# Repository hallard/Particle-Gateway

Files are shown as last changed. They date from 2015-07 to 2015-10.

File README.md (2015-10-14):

Particle (formerly Spark) Gateway
=================================

Edit October 2015 : New Revision 1.0a with better SMA connector for RF module

The gateway can host several funny things like

- Socket to plug a Spark Core or Particle Photon
- Pins to connect I2C or SPI OLED 128x64
- Pins to connect 2.2" or 1.8" TFT LCD
- RFM69 or RFM12B on board module
- Lipo Battery connector for testing and move the Gateway (no charger on board)
- 3V3 On board regulator for harvesting devices if any to avoid pumping from Particle Regulator
- Data connection for any cheap ebay ASK RX receiver
- FTDI connection for those who want to debug serial or send data over real serial
- 2 x grove I2C connector to connect other I2C devices

Detailed Description
====================

Everything is documented on this dedicated [post][1] 

### Schematic  
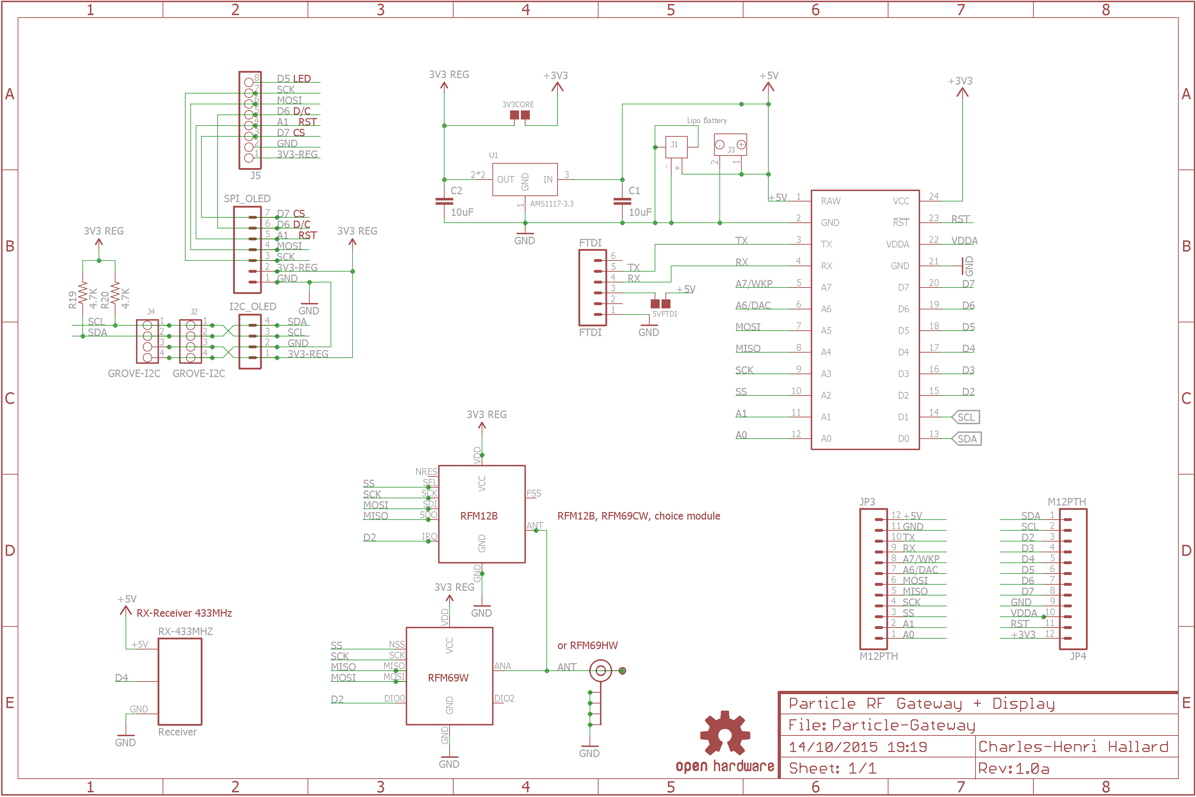
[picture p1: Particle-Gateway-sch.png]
schematic
  

### Bill Of Material
Reference from Seeedstudio [Open Part Libray][8] SKU but can be ordered on any provider, Digikey, Mouser. Link to the [BOM][6] file.    

For SPARK connector I use IC socket that I cut on needed size, for other connectors, I usually buy 40 pins headers (male and female) on ebay that I cut at the needed size. [Example][7]

### Boards  
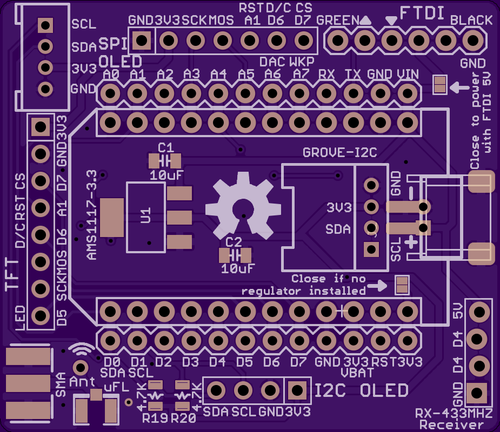
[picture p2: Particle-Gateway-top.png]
Top
&nbsp;
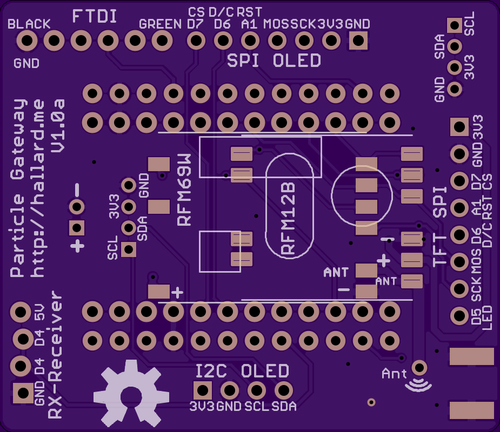
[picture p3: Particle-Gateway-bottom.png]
Bottom
&nbsp; 

You can order the PCB of this board at [OSHPARK][5]

### Assembled boards

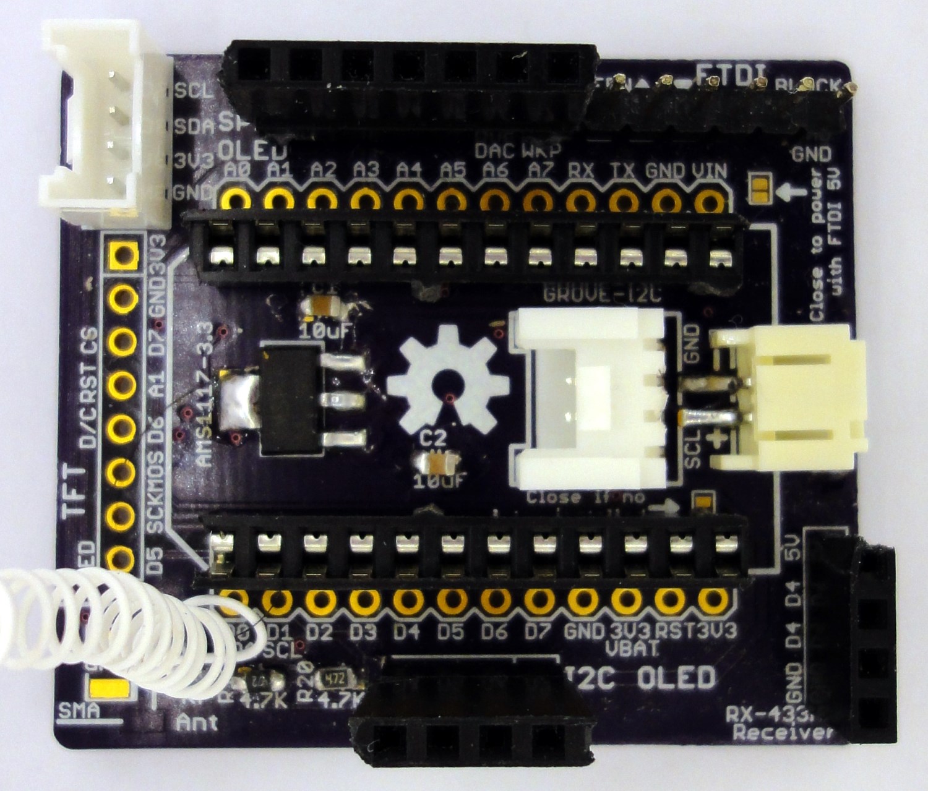
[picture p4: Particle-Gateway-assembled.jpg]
Assembled TOP
&nbsp;
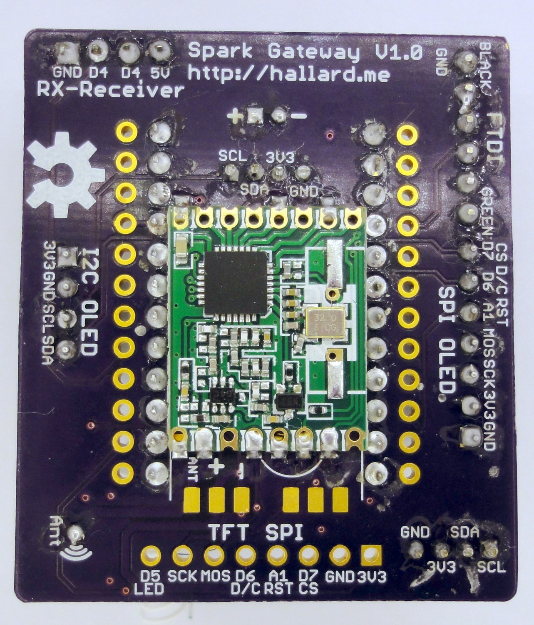
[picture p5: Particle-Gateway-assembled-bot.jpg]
Assembled Bottom

OLED&nbsp; 

##License

You can do whatever you like with this design.

##Misc
See news and other projects on my [blog][2] 
 
[1]: https://hallard.me/particle-gateway/
[2]: https://hallard.me
[3]: https://github.com/thibdct/programmateur-fil-pilote-wifi/tree/master/Logiciel/remora
[4]: http://lowpowerlab.com/blog/2013/06/20/rfm69-library/
[5]: https://oshpark.com/shared_projects/S3Dmdwhs
[6]: https://github.com/hallard/Particle-Gateway/blob/master/Particle-Gateway-BOM.xlsx?raw=true
[7]: http://stores.ebay.com/jkpartsstore/Connectors-Sockets-/_i.html?_fsub=1665035011
[8]: http://www.seeedstudio.com/depot/OPLopen-parts-library-catalog-c-136_138/?ref=side

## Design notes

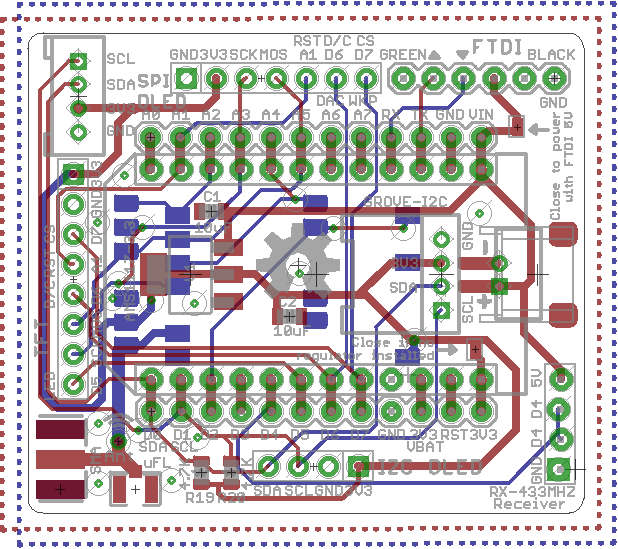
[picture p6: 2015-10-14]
Particle-Gateway-board.png

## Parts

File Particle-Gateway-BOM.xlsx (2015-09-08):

Part | Value | Device | Package | Description | SEEEDSTUDIO OPL SKU
C1 | 10uF | CAP0805-CAP | 0805-CAP | Capacitor | 302010178 (http://www.seeedstudio.com/depot/index.php?main_page=opl_info&opl_id=7)
C2 | 10uF | CAP0805-CAP | 0805-CAP | Capacitor | 302010178 (http://www.seeedstudio.com/depot/index.php?main_page=opl_info&opl_id=7)
FTDI | FTDI | M06SIP | 1X06 | 6x2.54mm male header | 320020078 (http://www.seeedstudio.com/depot/index.php?main_page=opl_info&opl_id=96)
I2C_OLED | CON_HEADER_1X04'SMALL'' | CON_HEADER_1X04'SMALL'' | M1X4 | 4x2.54mm Female connector | 320030017 (http://www.seeedstudio.com/depot/index.php?main_page=opl_info&opl_id=237)
J1 |  | JST-2P-SMD'2.0' | 2P-SMD-2.0-90D | Battery Connector (Use J1 or J3 not both) | 320110027 (http://www.seeedstudio.com/depot/index.php?main_page=opl_info&opl_id=64)
J2 | GROVE-I2C | GROVE-4P-2.0-3470140P1 | 4P-2.0-90D | Grove connector | 320110034 (http://www.seeedstudio.com/depot/index.php?main_page=opl_info&opl_id=24)
J3 | Lipo Battery | JST-2P-PW-3410070P1 | 2P-2.0-90D | Battery Connector (Use J1 or J3 not both) | 320110026 (http://www.seeedstudio.com/depot/index.php?main_page=opl_info&opl_id=37)
J4 | GROVE-I2C | GROVE-4P-2.0-3470130P1 | 4P-2.0 | Grove connector | 320110033 (http://www.seeedstudio.com/depot/index.php?main_page=opl_info&opl_id=4)
J5 | CON_HEADER_1X08-PTH | CON_HEADER_1X08-PTH | M1X8 | 8x2.54mm Female connector | 320030061 (http://www.seeedstudio.com/depot/index.php?main_page=opl_info&opl_id=95)
JP3 | M12PTH | M12PTH | 1X12-SMALL-PADS | Header 12
JP4 | M12PTH | M12PTH | 1X12-SMALL-PADS | Header 12
R19 | 4.7K | RESISTOR0805-RES | 0805-RES | Resistor | 301010306 (http://www.seeedstudio.com/depot/index.php?main_page=opl_info&opl_id=260)
R20 | 4.7K | RESISTOR0805-RES | 0805-RES | Resistor | 301010306 (http://www.seeedstudio.com/depot/index.php?main_page=opl_info&opl_id=260)
SPI_OLED | CON_HEADER_1X07'SMALL' | CON_HEADER_1X07'SMALL' | M1X7 | 7x2.54mm Female connector | 320020093 (http://www.seeedstudio.com/depot/index.php?main_page=opl_info&opl_id=997)
U1 | AMS1117-3.3 | CJ1117-3.3-1310190P1 | SOT223 | 3V3 1A Low Dropout Linear Regulator | 310030097 (http://www.seeedstudio.com/depot/index.php?main_page=opl_info&opl_id=33)

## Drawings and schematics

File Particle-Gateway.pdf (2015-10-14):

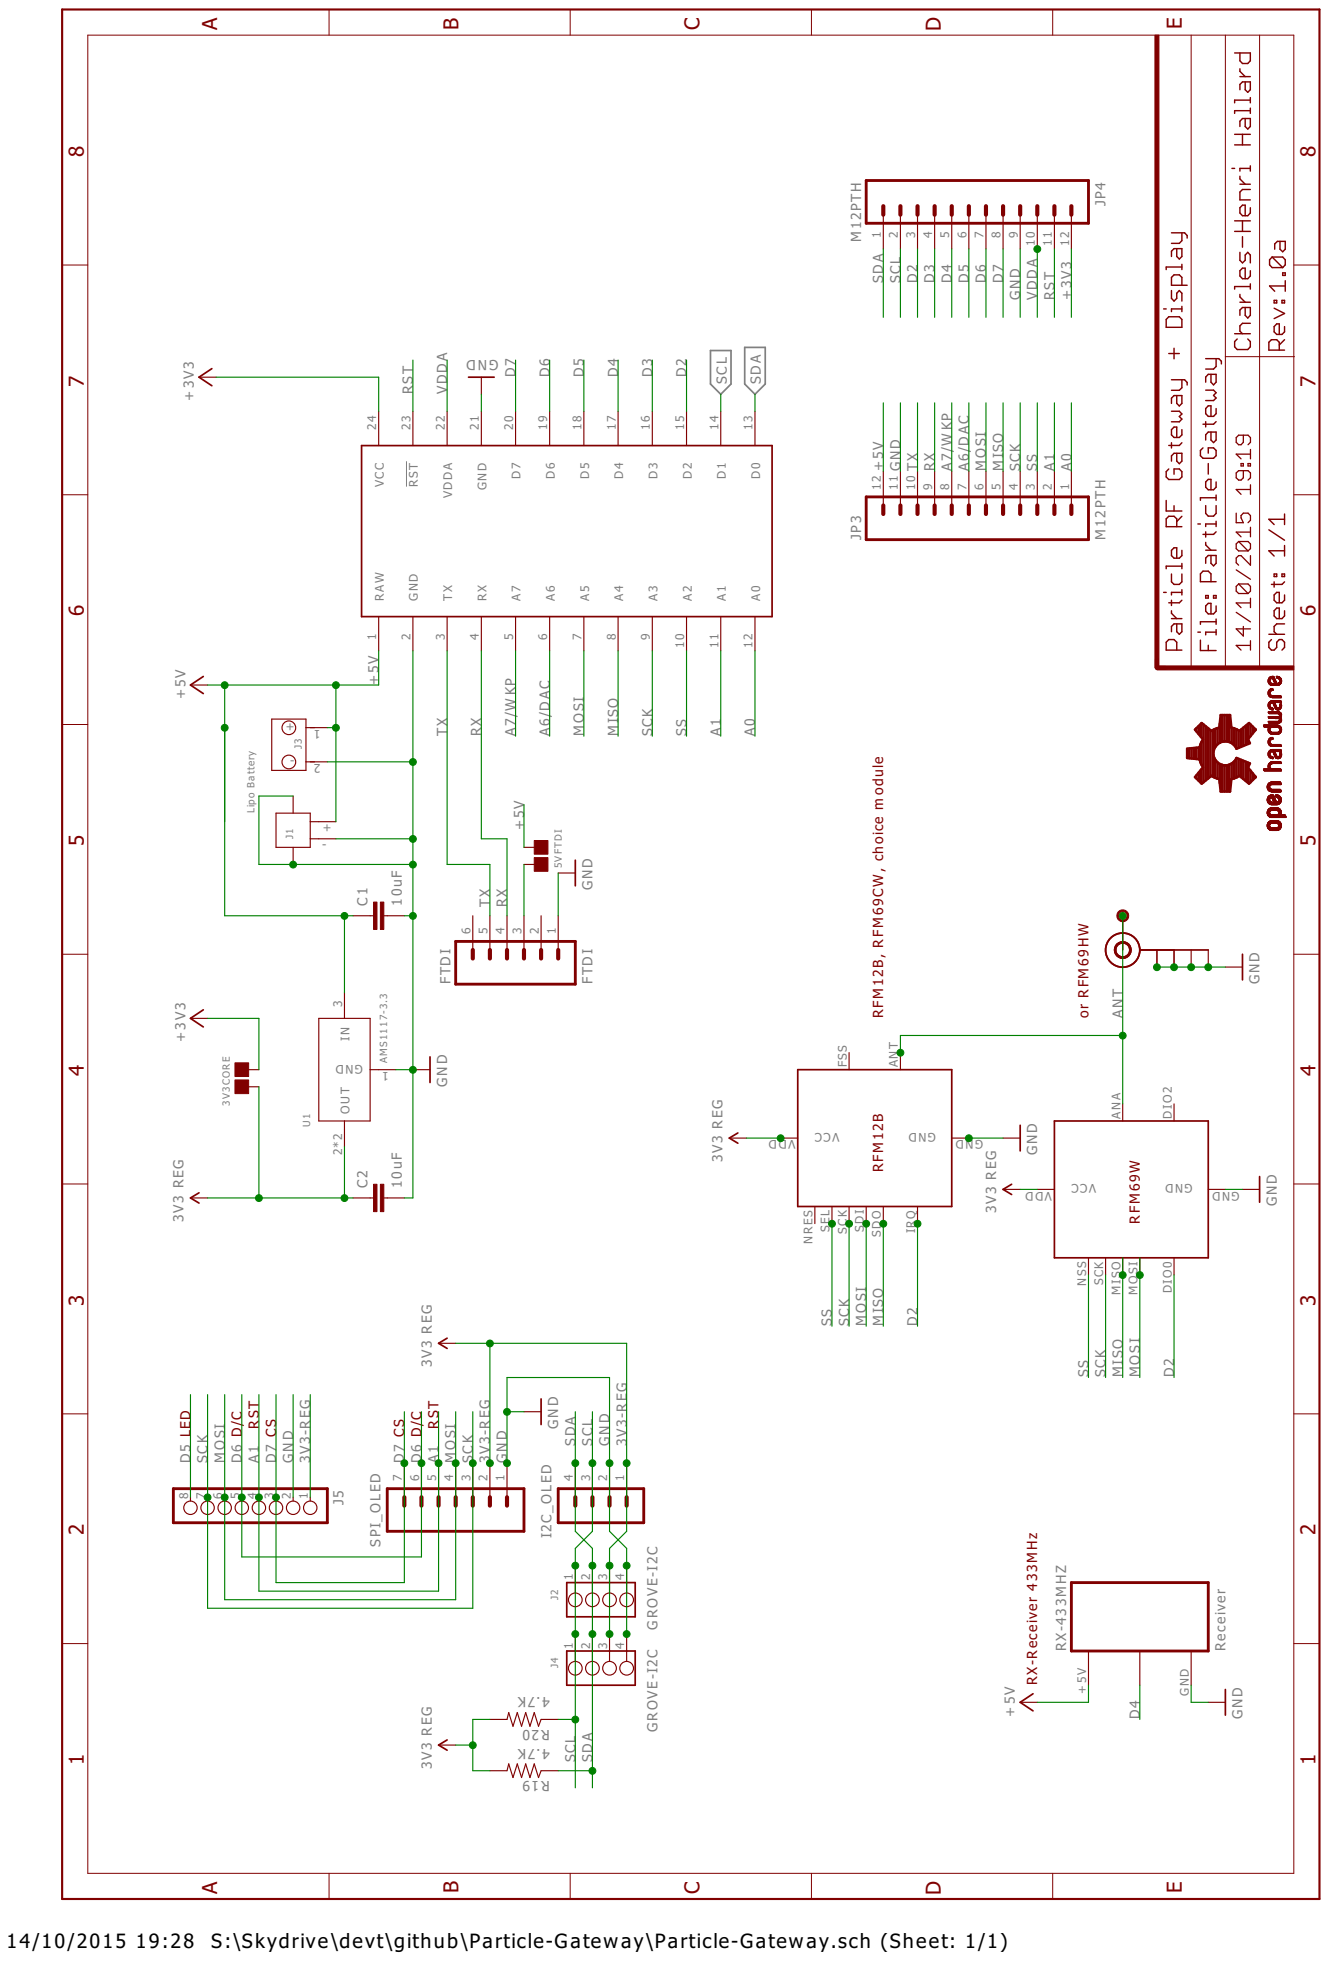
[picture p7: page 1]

MISO MOSI SCK NSS CCV DDV

14/10/2015 19:28 S:\Skydrive\devt\github\Particle-Gateway\Particle-Gateway.sch (Sheet: 1/1)

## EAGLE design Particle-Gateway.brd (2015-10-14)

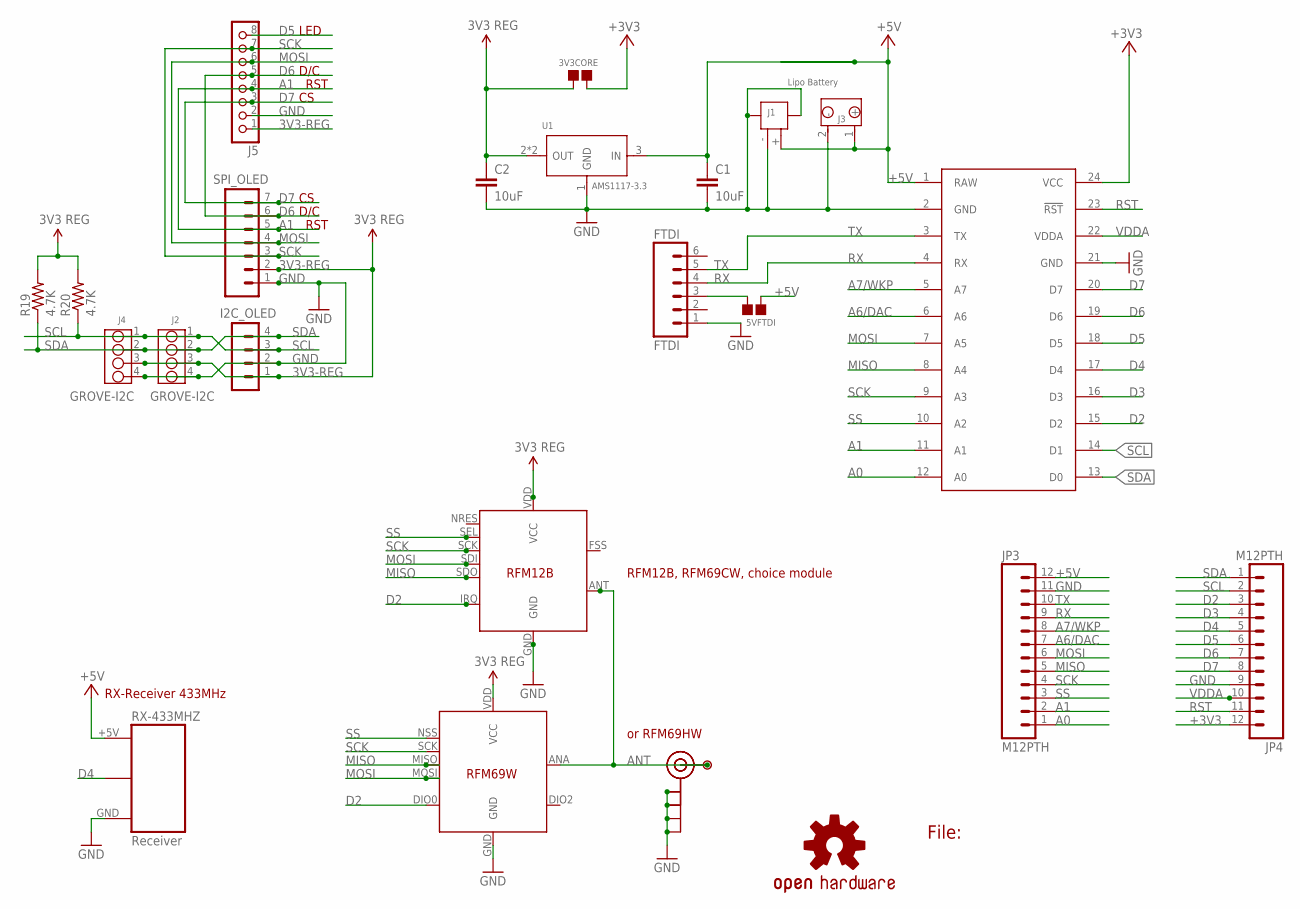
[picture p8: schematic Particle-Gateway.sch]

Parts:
3V3CORE, 5VFTDI: PAD-JUMPER-2P; 2P-SMD-1.78X1.27
C1, C2: 10uF; 0805-CAP
FTDI: FTDI; 1X06
I2C_OLED: CON_HEADER_1X04'SMALL''; M1X4
J1: JST-2P-SMD'2.0'; 2P-SMD-2.0-90D
J2: GROVE-I2C; 4P-2.0-90D
J3: Lipo Battery; 2P-2.0-90D
J4: GROVE-I2C; 4P-2.0
J5: CON_HEADER_1X08-PTH; M1X8
J$1: SMA_EDGE; SMA-EDGE
JP3, JP4: M12PTH; 1X12-SMALL-PADS
LOGO2: OSHW-LOGOL; OSHW-LOGO-L
P1: PADSMALL; PAD-SMALL
R19, R20: 4.7K; 0805-RES
RX-433MHZ: Receiver; RF-LINK_RX_NO_SILK
SPARKCORE: SPARK_CORECORE; SPARK_CORE
SPI_OLED: CON_HEADER_1X07'SMALL'; M1X7
U1: AMS1117-3.3; SOT223
U$2: RFM12B; RFM12B-MINPADS
U$3: RFM69W; RFM69W-MINPADS
U-FL: U.FL

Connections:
3V3-REG: 3V3CORE.1, C2.1, I2C_OLED.1, J2.3, J4.3, J5.1, R19.2, R20.2, SPI_OLED.2, U1.2 (OUT), U1.TER (OUT), U$2.VDD (VCC), U$3.VDD (VCC)
+3V3: 3V3CORE.2, JP4.12, SPARKCORE.24 (VCC)
+5V: 5VFTDI.1, C1.1, J1.+ (1), J3.1 (+), JP3.12, RX-433MHZ.+5V, SPARKCORE.1 (RAW), U1.3 (IN)
A0: JP3.1, SPARKCORE.12 (A0)
A1: J5.4, JP3.2, SPARKCORE.11 (A1), SPI_OLED.5
A6/DAC: JP3.7, SPARKCORE.6 (A6)
A7/WKP: JP3.8, SPARKCORE.5 (A7)
ANT: J$1.SIG (SIGNAL), P1.1, U$2.ANT, U$3.ANA (ANT), U-FL.3 (SIGNAL)
D2: JP4.3, SPARKCORE.15 (D2), U$2.IRQ, U$3.DIO0
D3: JP4.4, SPARKCORE.16 (D3)
D4: JP4.5, RX-433MHZ.DATA@1 (DATA), RX-433MHZ.DATA@2 (DATA), SPARKCORE.17 (D4)
D5: J5.8, JP4.6, SPARKCORE.18 (D5)
D6: J5.5, JP4.7, SPARKCORE.19 (D6), SPI_OLED.6
D7: J5.3, JP4.8, SPARKCORE.20 (D7), SPI_OLED.7
GND: C1.2, C2.2, FTDI.1, I2C_OLED.2, J1.3, J1.4, J1.- (2), J2.4, J3.2 (-), J4.4, J5.2, J$1.GND@0 (GND), J$1.GND@1 (GND), J$1.GND@2 (GND), J$1.GND@3 (GND), JP3.11, JP4.9, RX-433MHZ.GND, SPARKCORE.2 (GND), SPARKCORE.21 (GND), SPI_OLED.1, U1.1 (GND), U$2.GND, U$3.GND, U-FL.1 (GND), U-FL.2 (GND)
MISO: JP3.5, SPARKCORE.8 (A4), U$2.SDO, U$3.MISO
MOSI: J5.6, JP3.6, SPARKCORE.7 (A5), SPI_OLED.4, U$2.SDI, U$3.MOSI
unnamed: 5VFTDI.2, FTDI.3
RST: JP4.11, SPARKCORE.23 (!RST)
RX: FTDI.4, JP3.9, SPARKCORE.4 (RX)
SCK: J5.7, JP3.4, SPARKCORE.9 (A3), SPI_OLED.3, U$2.SCK, U$3.SCK
SCL: I2C_OLED.3, J2.1, J4.1, JP4.2, R20.1, SPARKCORE.14 (D1)
SDA: I2C_OLED.4, J2.2, J4.2, JP4.1, R19.1, SPARKCORE.13 (D0)
SS: JP3.3, SPARKCORE.10 (A2), U$2.SEL, U$3.NSS (SEL)
TX: FTDI.5, JP3.10, SPARKCORE.3 (TX)
VDDA: JP4.10, SPARKCORE.22 (VDDA)

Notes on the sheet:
RFM12B, RFM69CW, choice module
or RFM69HW
RX-Receiver 433MHz
D/C
LED
RST
File:

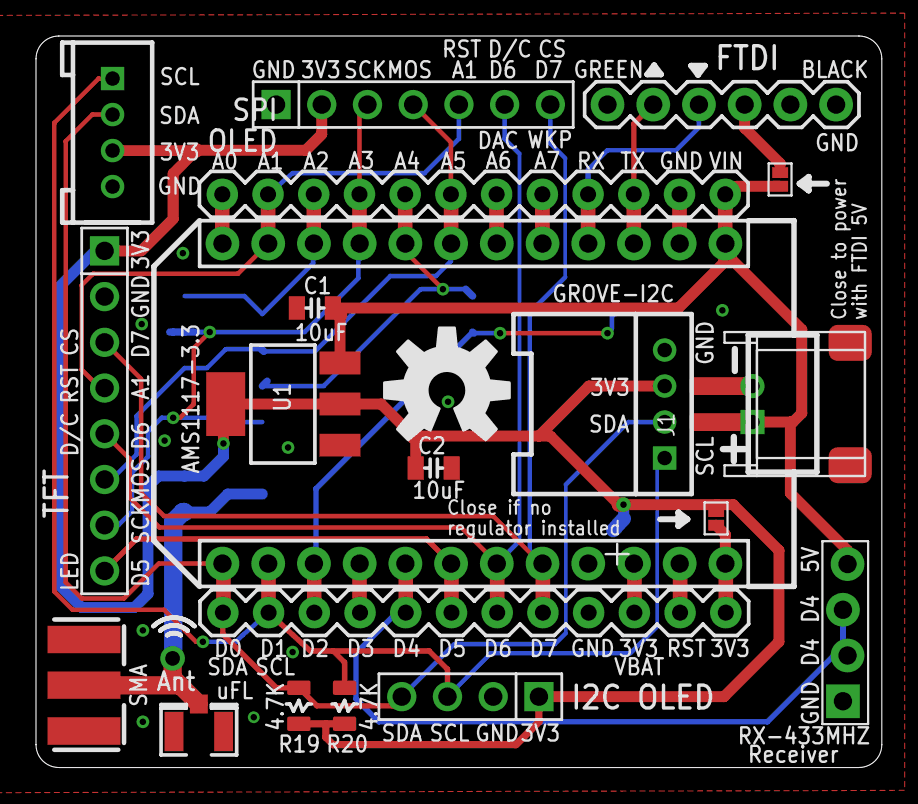
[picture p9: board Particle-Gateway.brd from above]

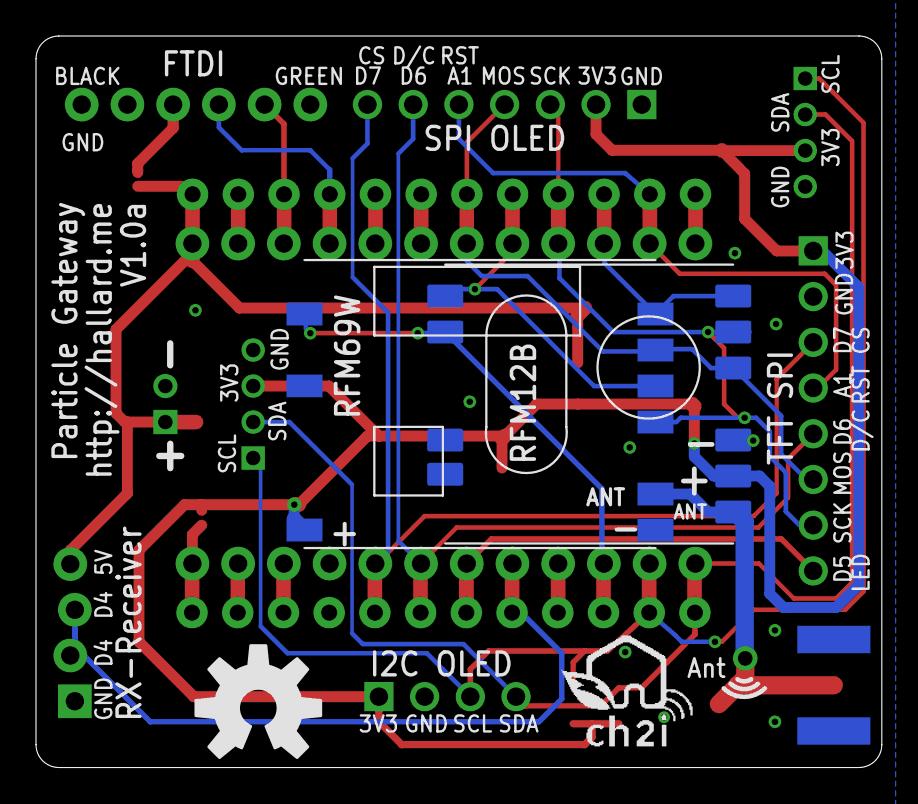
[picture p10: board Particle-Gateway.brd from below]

Board: 2 copper layers, 47.0 x 40.6 mm, 27 parts (4 on the bottom side), 26 nets.

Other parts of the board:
LOGO1: OSHW-LOGOL; OSHW-LOGO-L
U$1: LOGO_CH2I_75MM

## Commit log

2015-09-08 Added BOM links
2015-09-08 Removed BOM link problem
2015-10-14 Adjusted SMA connector exposed PAD
    [Particle-Gateway.brd, Particle-Gateway.sch]

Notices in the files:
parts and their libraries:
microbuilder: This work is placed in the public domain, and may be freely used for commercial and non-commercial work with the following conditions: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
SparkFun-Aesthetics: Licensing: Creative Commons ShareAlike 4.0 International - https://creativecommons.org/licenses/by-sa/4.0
